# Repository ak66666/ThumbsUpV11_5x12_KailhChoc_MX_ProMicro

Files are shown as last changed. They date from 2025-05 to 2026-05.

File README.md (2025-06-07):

# ThumbsUp! v11 5x12 Keyboard for Kailh Choc and MX-compatible switches dirven by ProMicro and pin-compatibles

Multilevel 58 Key Ergonomic Contoured Mechanical Keyboard.

A variant of v5 and v8 for this specific combination of switches, plus with extra pins for MCU to make ProGlide Cirque touchpad work in ZMK.
Added slots on the PCBs to cut off the top row and outer columns, to turn the board into a 4x12 or 5x10 or 4x10, moved the tracks out of the way for those cuts.

The board uses Kailh Choc and MX-compatible switches with hot-swap sockets.

ProMicro or pin-compatible MCUs are supported, including Raspberry RP2040, nice!nano v2 and clones.

Supports Proglide Cirque touchpad (up to 40mm diameter).

Can be made wireless with nice!nano v2 (or a clone) and a battery, [ZMK firmware.](https://github.com/ak66666/zmk-config/tree/master)

# Photos

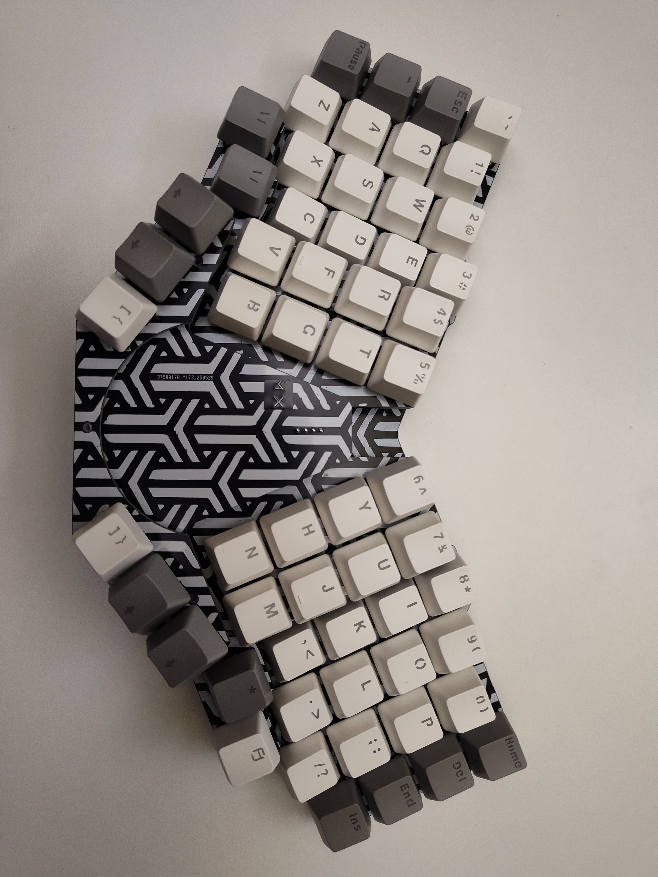
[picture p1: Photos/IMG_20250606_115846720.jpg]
v11 complete with MX switches and caps

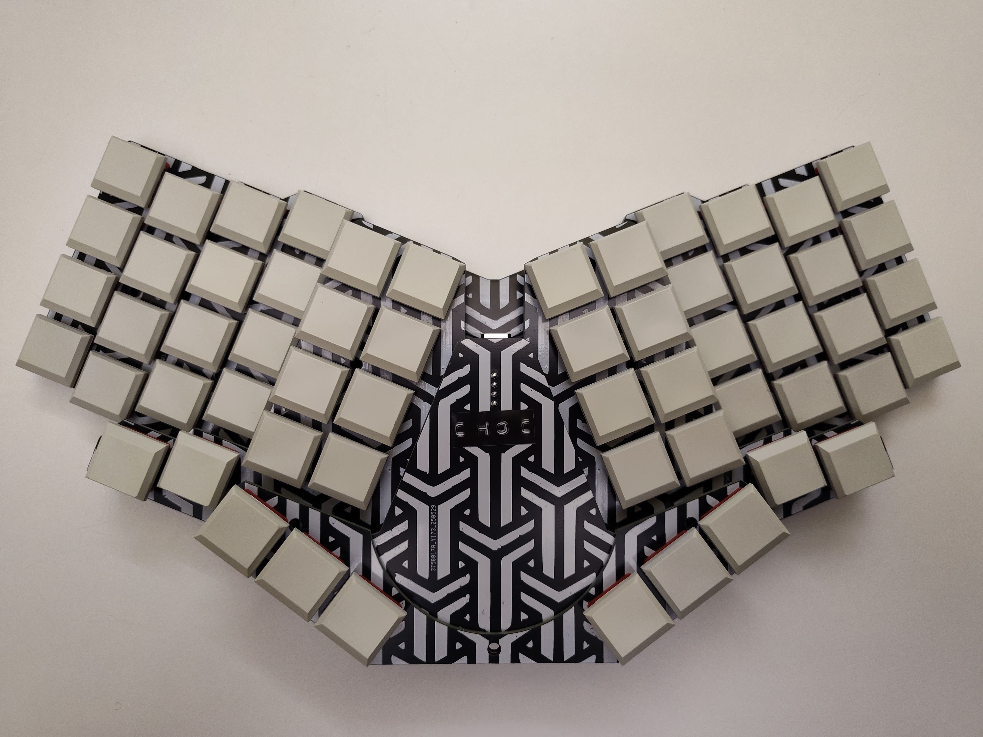
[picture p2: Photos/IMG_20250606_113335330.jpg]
v11 complete with Kailh Choc switches and caps

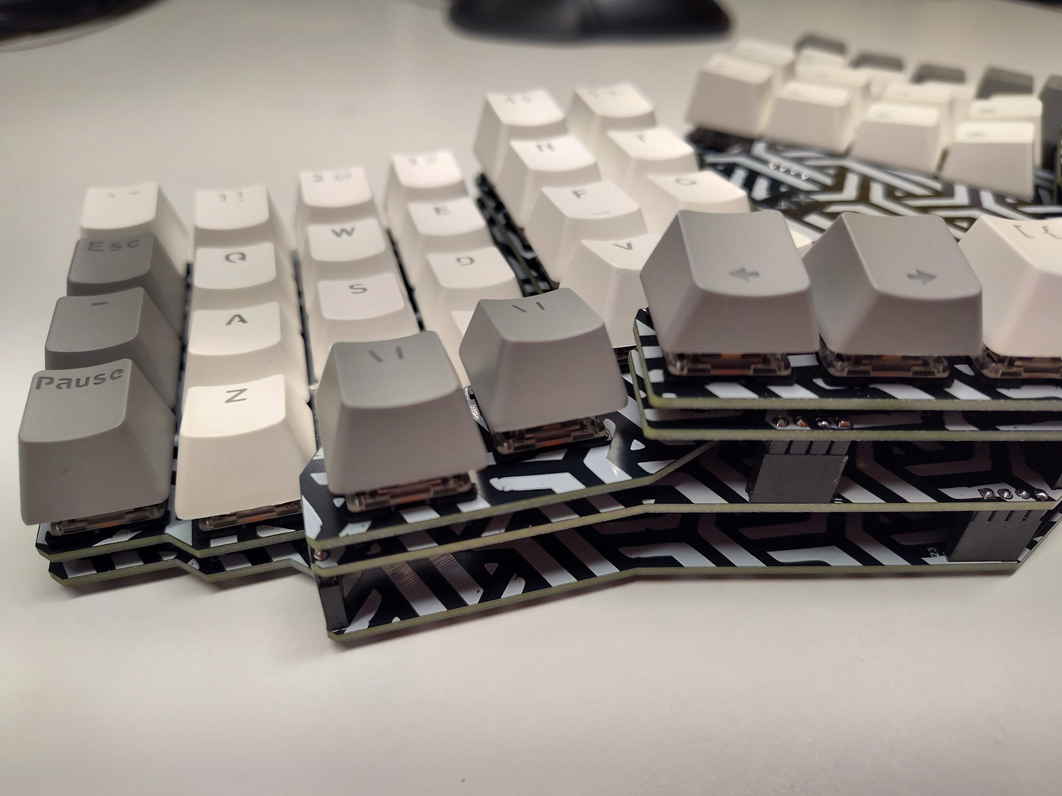
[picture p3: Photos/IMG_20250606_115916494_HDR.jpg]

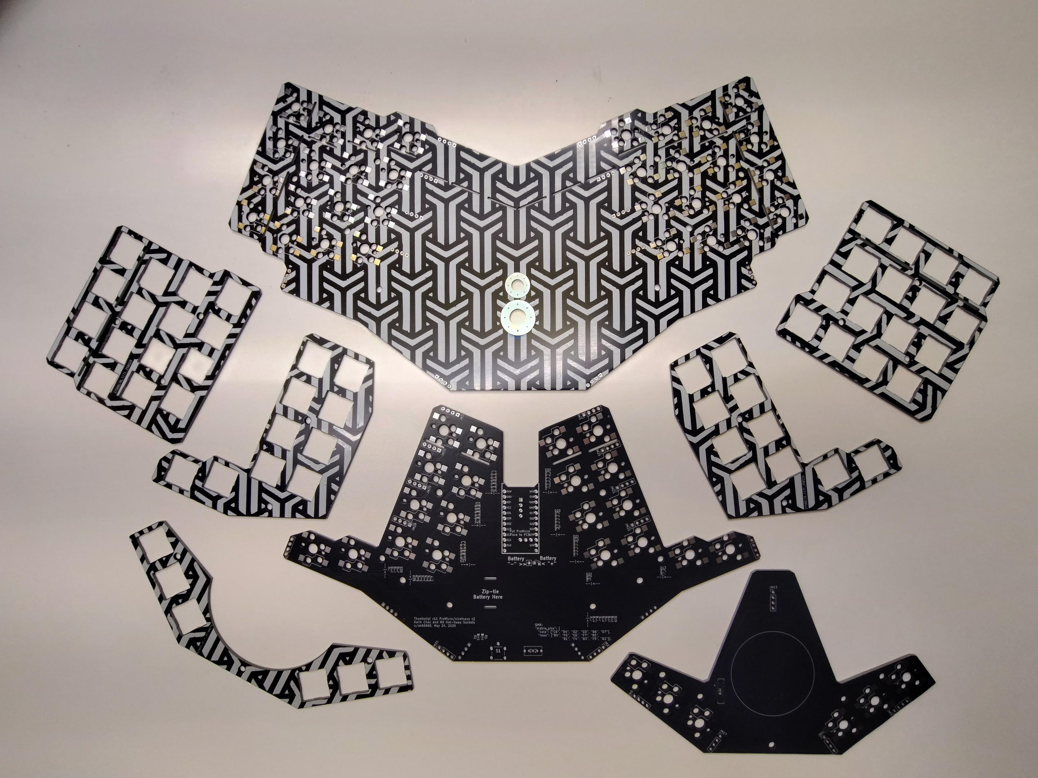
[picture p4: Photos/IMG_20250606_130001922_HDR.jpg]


See more pictures in Photos folder. 

# Firmware
Default firmware is here:
QMK Firmware
Note this board uses the firmware from v5 - it got the very same wiring.

# Here you can buy it
ThumbsUp! v11

# More info

Usage instructions and miscellaneous info:
Blogspot

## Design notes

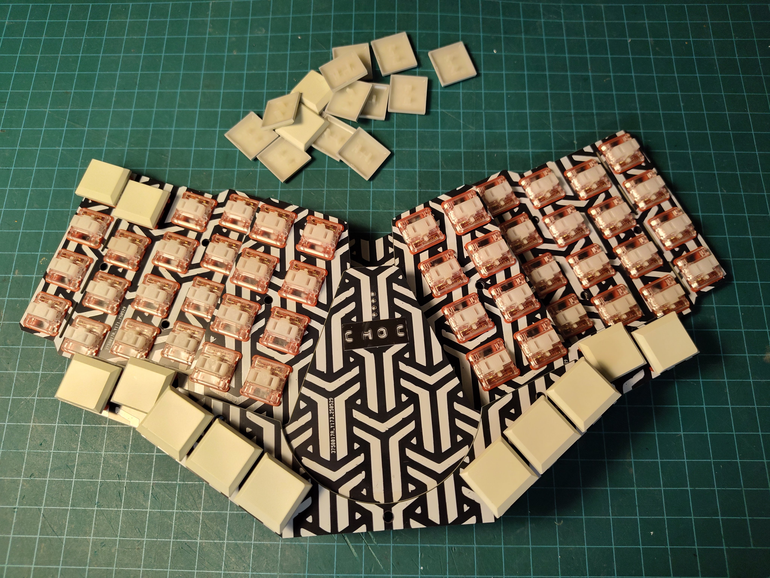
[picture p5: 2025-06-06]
Photos/IMG_20250606_111325914_HDR.jpg

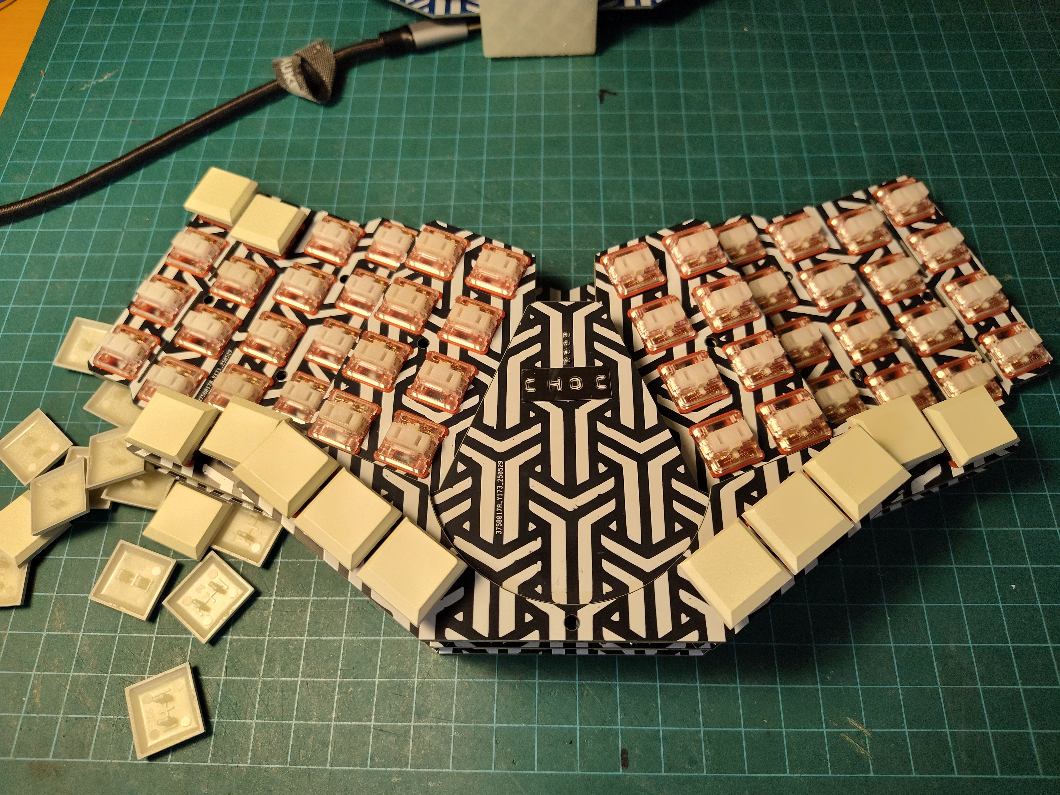
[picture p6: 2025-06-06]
Photos/IMG_20250606_111258978_HDR.jpg

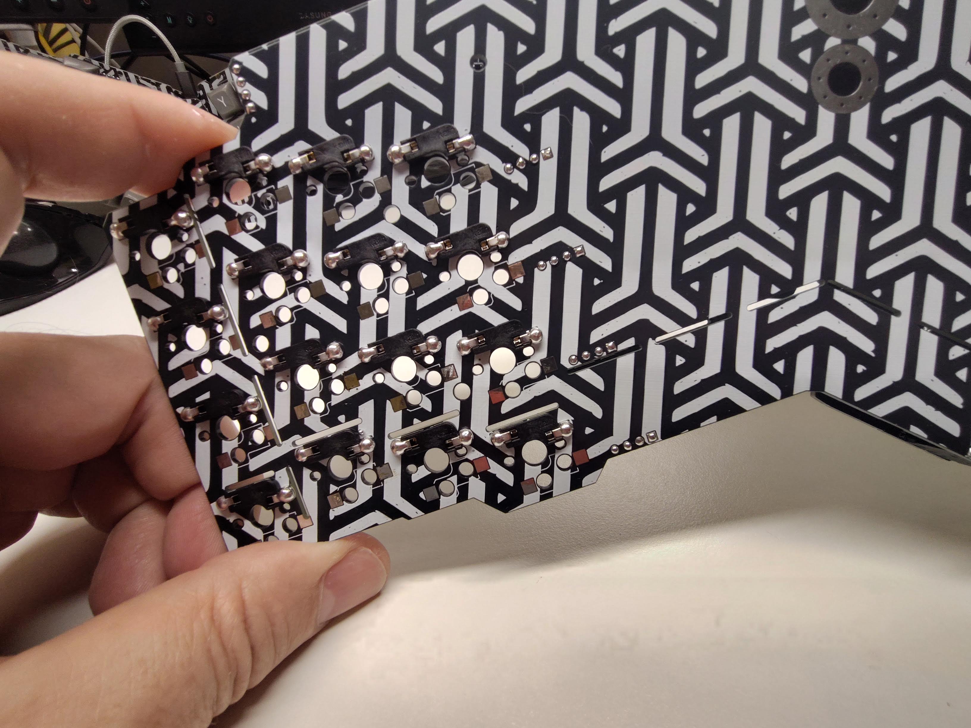
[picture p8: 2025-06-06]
Photos/IMG_20250605_220522538_HDR.jpg

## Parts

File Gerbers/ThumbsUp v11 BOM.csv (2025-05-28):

Designator | Footprint | Quantity | Comment | JLCPCB Part #
D49,D50,D55,D54,D57,D56,D52,D58,D51,D14,D53,D35,D34,D42,D40,D48,D45,D43,D46,D47,D38,D41,D39,D37,D36,D44,D33,D32,D31,D16,D15,D13,D12,D30,D29,D27,D25,D28,D24,D22,D21,D23,D20,D19,D26,D18,D17,D5,D7,D4,D6,D9,D10,D1,D8,D11,D3,D2 | D_SOD-523 | 58 | D_Small | C27748
R2,R1 | R_0805_2012Metric | 2 | 5.1K | C27834

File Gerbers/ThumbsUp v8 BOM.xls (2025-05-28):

Comment | Designator | Footprint | JLCPCB Part #
D_Small | D58,D57,D56,D55,D54,D53,D52,D51,D50,D49,D48,D47,D46,D45,D44,D43,D42,D41,D40,D39,D38,D37,D36,D35,D34,D33,D32,D31,D30,D29,D28,D27,D26,D25,D24,D23,D22,D21,D20,D19,D18,D17,D16,D15,D14,D13,D12,D11,D10,D9,D8,D7,D6,D5,D4,D3,D2,D1 | D_SOD-123 | C81598
5.1K | R2,R1 | R_0805_2012Metric | C27834

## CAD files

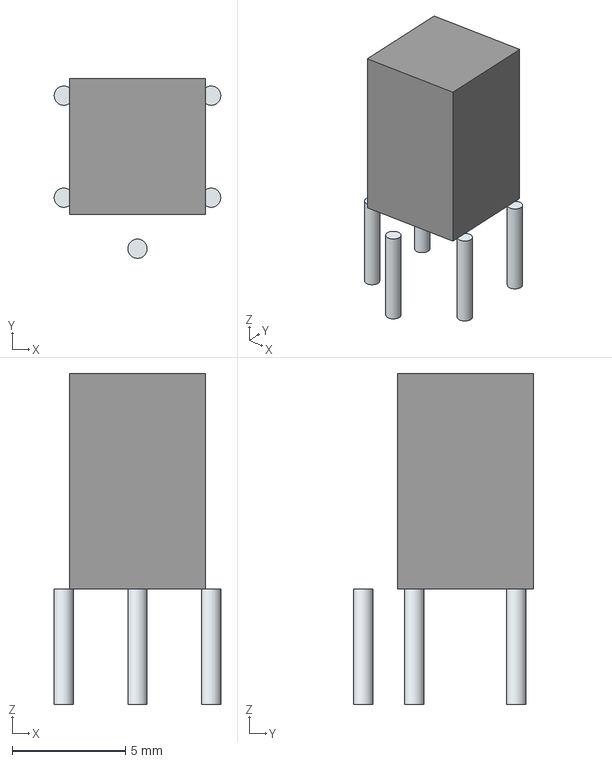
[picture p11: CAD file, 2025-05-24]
LIB_BUTT-4/BUTT-4/3D/BUTT-4.stp
7.35 x 7.92 x 14.6 mm
Leads x 5

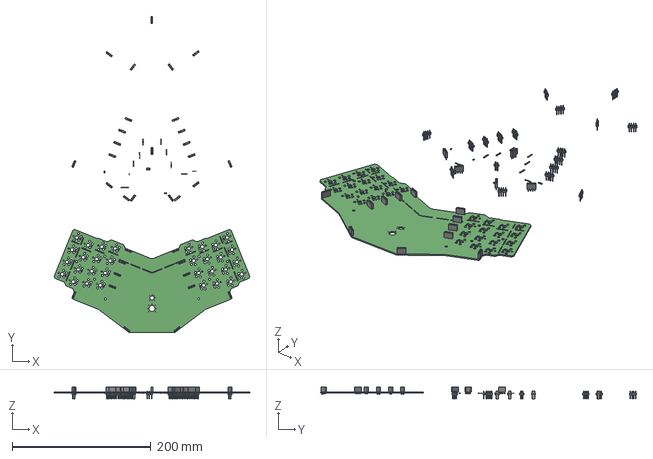
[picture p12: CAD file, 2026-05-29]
ThumbsUp_v11.step
282.0 x 455.3 x 17.2 mm

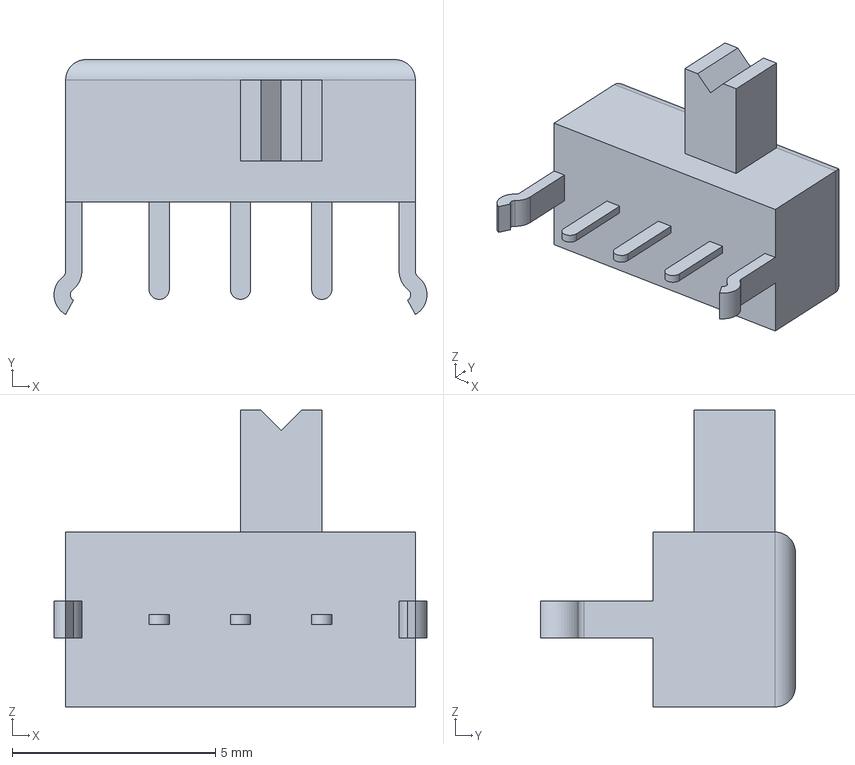
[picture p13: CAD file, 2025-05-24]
1825232-1/3D/1825232-1.stp
9.17 x 6.27 x 7.30 mm

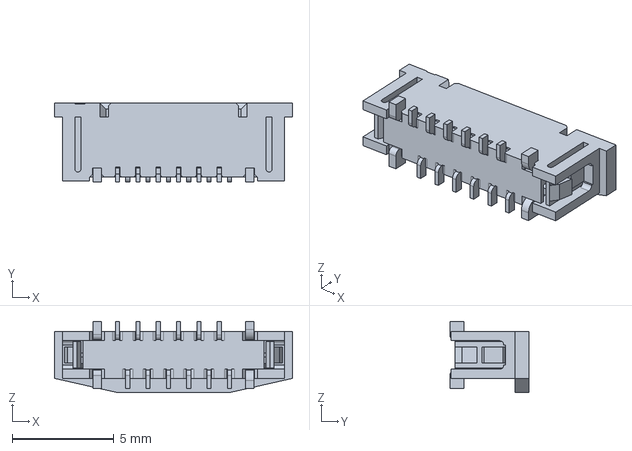
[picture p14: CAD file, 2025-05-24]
Molex 52559-1233/52559-1233/3D/52559-1233.stp
11.7 x 3.90 x 3.50 mm

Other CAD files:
1825232-1/Allegro/18252321.psm
1825232-1/DEHDL/1825232_1/chips/chips.prt
LIB_BUTT-4/BUTT-4/Allegro/butt4.psm
LIB_BUTT-4/BUTT-4/DEHDL/butt_4/chips/chips.prt
Molex 52559-1233/52559-1233/Allegro/525591233.psm
Molex 52559-1233/52559-1233/DEHDL/52559_1233/chips/chips.prt

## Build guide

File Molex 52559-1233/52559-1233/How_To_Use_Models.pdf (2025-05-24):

ECAD PART WIZARD.

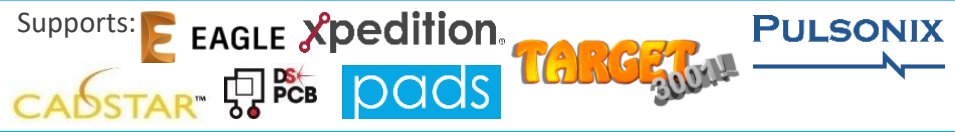
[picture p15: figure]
Supports:

Offers engineers full control of the symbol fracturing and symbol pin positions (left, right, top, bottom). ECAD Symbols & footprints can be downloaded directly from within the EPW application or from manufacturer and RS Component website.

DOWNLOAD: http://componentsearchengine.com/EPW.html

LIBRARY LOADER.
Allows Engineers to click our icon from any webpage and it injects the symbols and footprint directly into your chosen library and attached them to your cursor ready for placement.

DOWNLOAD: http://componentsearchengine.com/LibraryLoader.php

SamacSys is a leading developer of software tools for creating and managing electronic component ECAD data.

## 3 ways to use our ECAD Schematic Symbols & PCB footprints

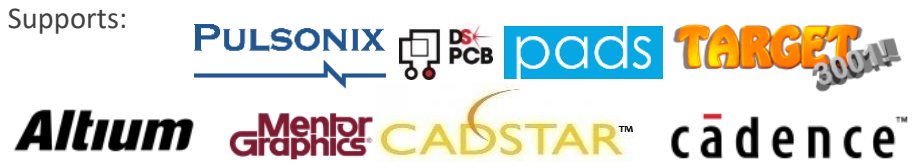
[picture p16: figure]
Supports:

DIRECT MODEL DOWNLOAD FOR MANUAL USE.
Our Schematic Symbols and PCB Footprint can be downloaded in a zip file for the user to manually load into their existing ECAD Library.

DOWNLOAD: http://componentsearchengine.com

Automatically load
models into your
library and attach
them to your cursor
by clicking our icon
on any website.

WATCH VIDEO (https://componentsearchengine.com/pcb-libraries.php)

Excel plug in. Search
for parts from within
Excel, customise the
fracturing and export
to your chosen ECAD
Tool.

WATCH VIDEO (http://www.samacsys.com/epw/)

You may download our
symbols & footprints in
the format of your
ECAD system for
manually loading into
your library.

MORE INFO (http://www.samacsys.com/pcb-part-libraries/)

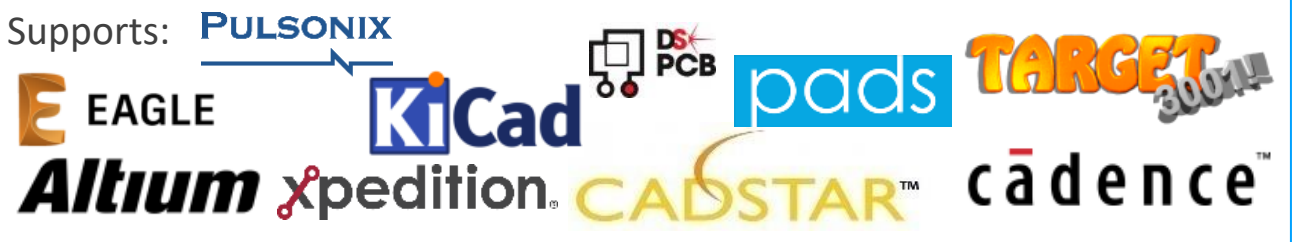
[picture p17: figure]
Supports:

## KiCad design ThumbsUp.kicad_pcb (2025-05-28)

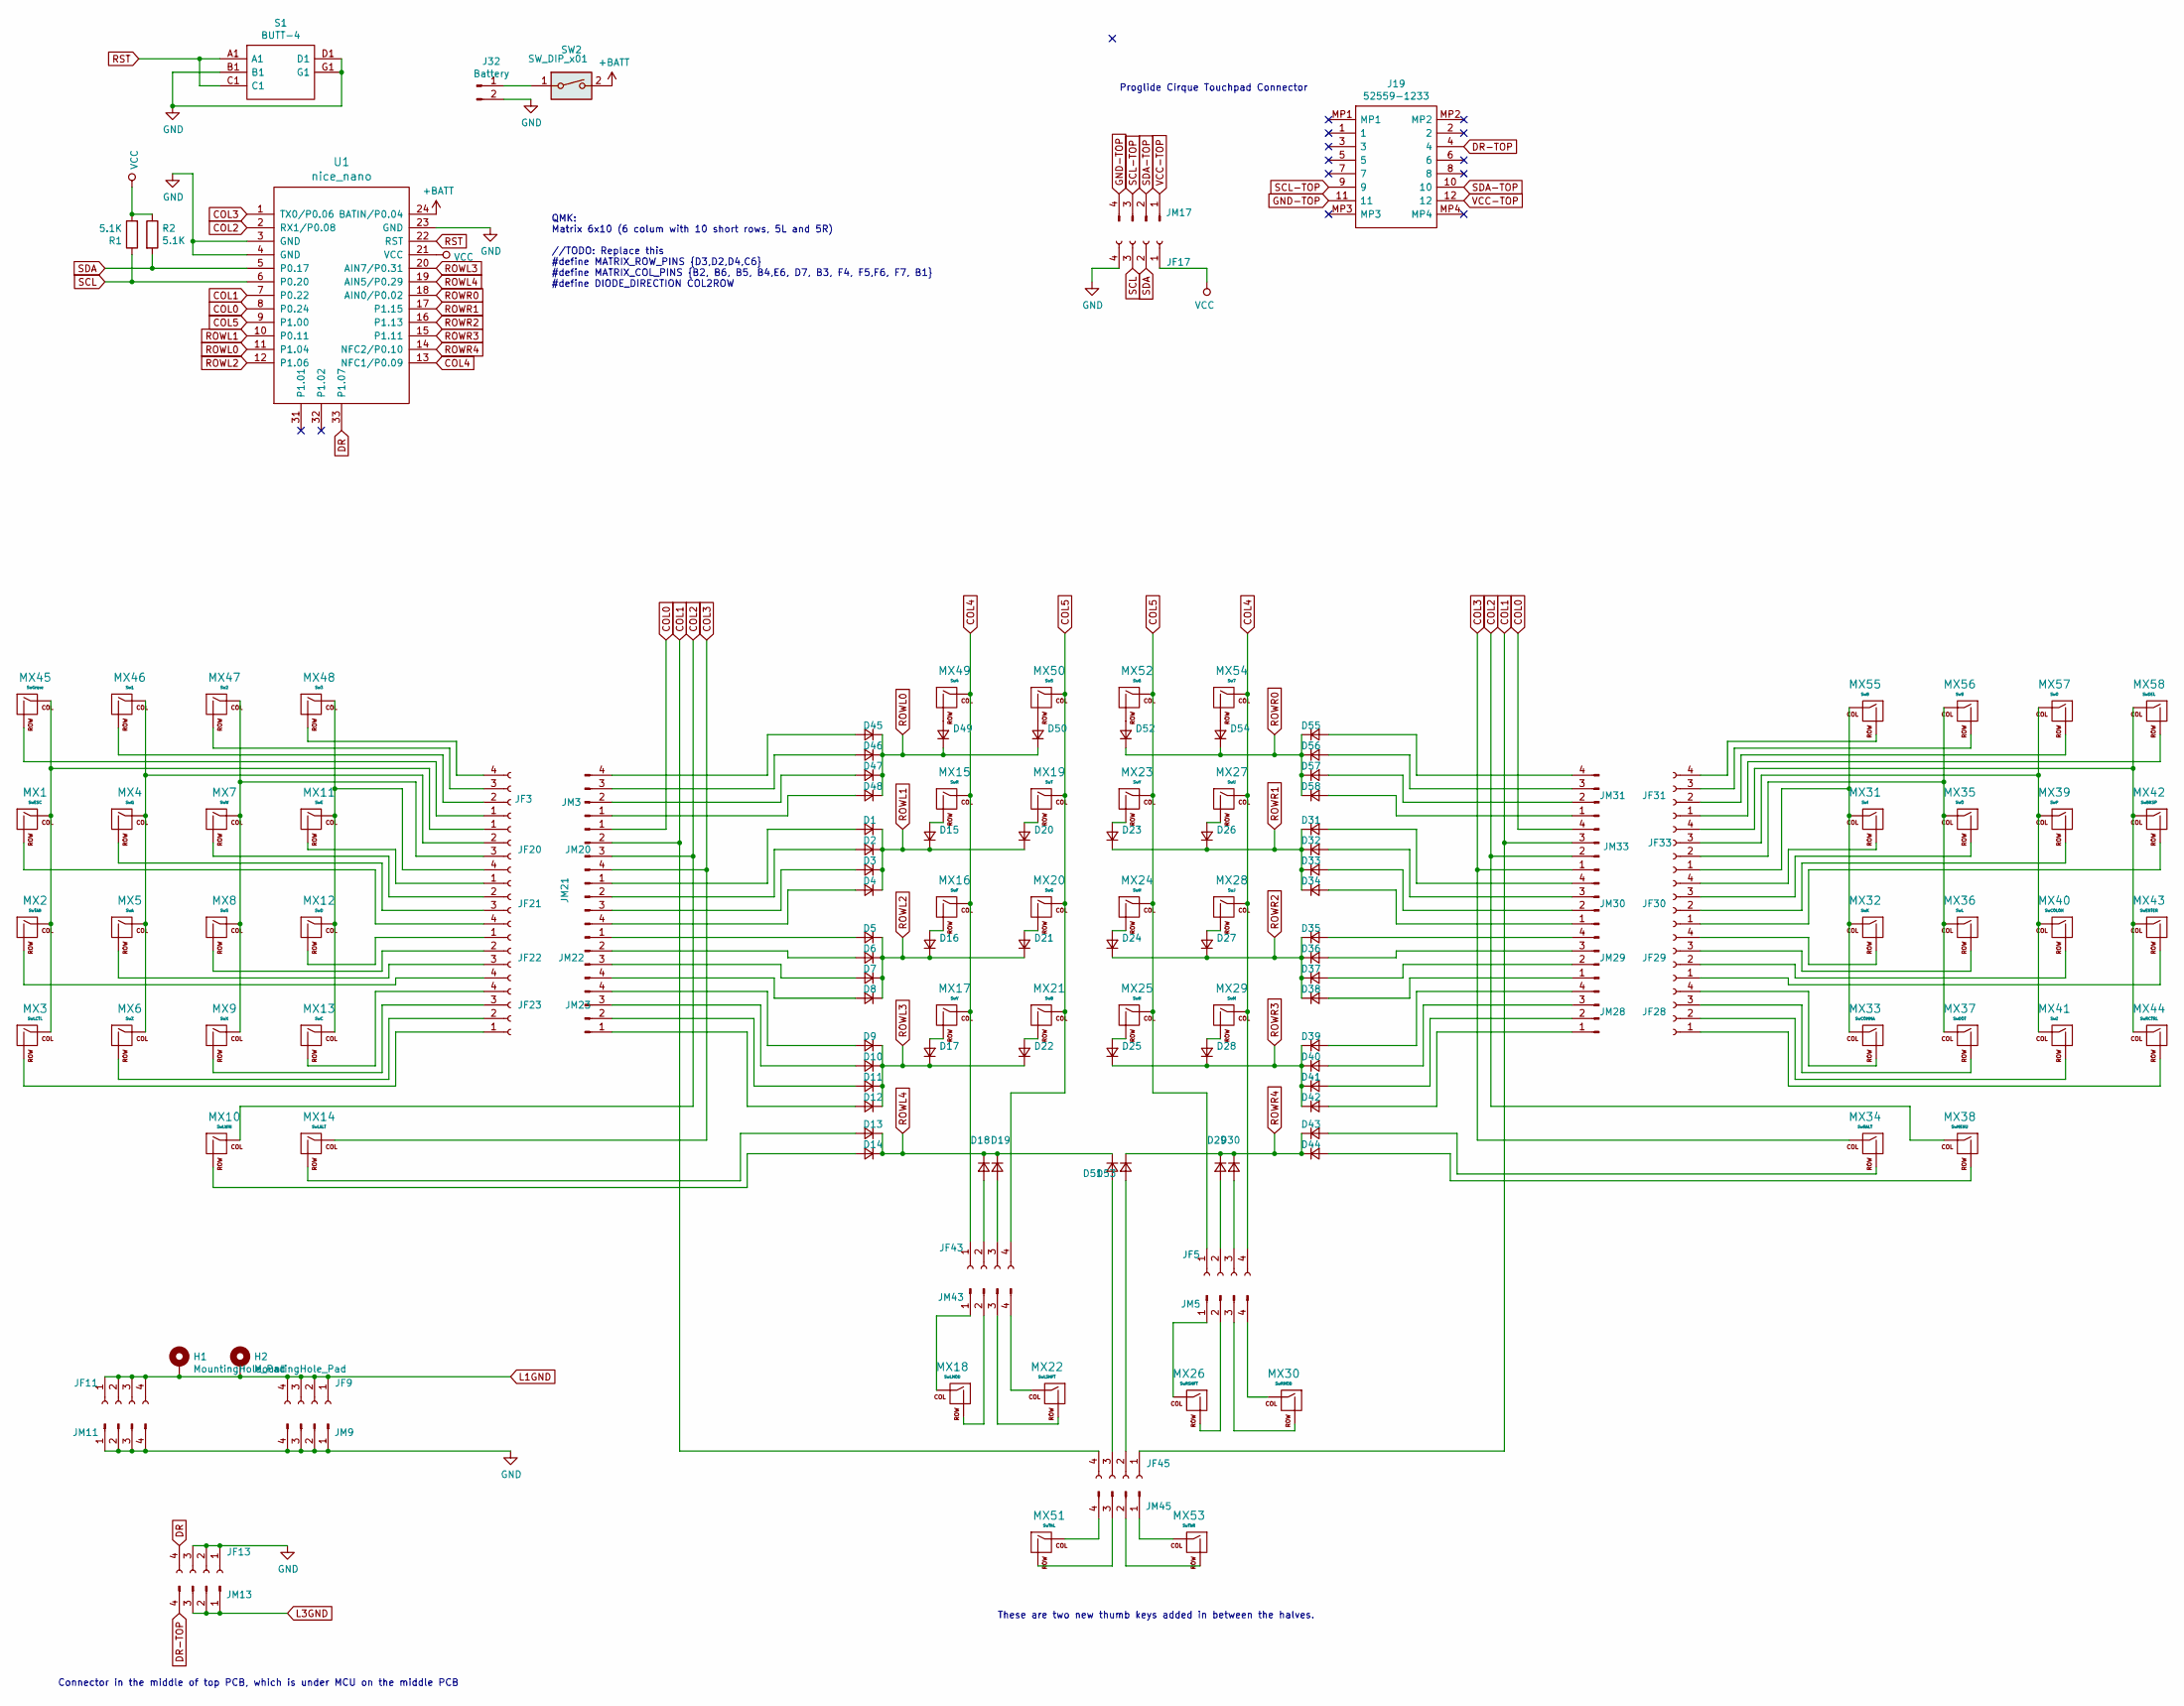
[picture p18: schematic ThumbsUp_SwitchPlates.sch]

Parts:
D1, D2, D3, D4, D5, D6, D7, D8, D9, D10, D11, D12, D13, D14, D15, D16, D17, D18, D19, D20, D21, D22, D23, D24, D25, D26, D27, D28, D29, D30, D31, D32, D33, D34, D35, D36, D37, D38, D39, D40, D41, D42, D43, D44, D45, D46, D47, D48, D49, D50, D51, D52, D53, D54, D55, D56, D57, D58: D_Small; D_SOD-523
H1: MountingHole_Pad; MountingHole_6mm_Pad_Via
H2: MountingHole_Pad; MountingHole_8.4mm_M8_Pad_Via
J19: 52559-1233; 525591233; Mouser Part Number 538-52559-1233
J32: Battery; PinHeader_1x02_P2.54mm_Vertical
JF3, JF5, JF20, JF21, JF22, JF23, JF28, JF29, JF30, JF31, JF33, JF43, JF45: Conn_01x04_Female; PinSocket_1x04_P2.54mm_Vertical
JF9, JF11, JF13, JF17: Raiser_Female; PinSocket_1x04_P2.54mm_Vertical
JM3, JM20, JM21, JM22, JM23, JM28, JM29, JM30, JM31, JM33, JM43, JM45: Conn_01x04_Male; PinHeader_1x04_P2.54mm_Vertical
JM5: Male; PinHeader_1x04_P2.54mm_Vertical
JM9, JM11, JM13, JM17: Raiser_Male; PinHeader_1x04_P2.54mm_Vertical
MX1: SwESC; PG1350_MX_sockets
MX2: SwTAB; PG1350_MX_sockets
MX3: SwLCTL; PG1350_MX_sockets
MX4: SwQ; PG1350_MX_sockets
MX5: SwA; PG1350_MX_sockets
MX6: SwZ; PG1350_MX_sockets
MX7: SwW; PG1350_MX_sockets
MX8: SwS; PG1350_MX_sockets
MX9: SwX; PG1350_MX_sockets
MX10: SwLWIN; PG1350_MX_sockets
MX11: SwE; PG1350_MX_sockets
MX12: SwD; PG1350_MX_sockets
MX13: SwC; PG1350_MX_sockets
MX14: SwLALT; PG1350_MX_sockets
MX15: SwR; PG1350_MX_sockets
MX16: SwF; PG1350_MX_sockets
MX17: SwV; PG1350_MX_sockets
MX18: SwLMOD; PG1350_MX_sockets
MX19: SwT; PG1350_MX_sockets
MX20: SwG; PG1350_MX_sockets
MX21: SwB; PG1350_MX_sockets
MX22: SwLSHFT; PG1350_MX_sockets
MX23: SwY; PG1350_MX_sockets
MX24: SwH; PG1350_MX_sockets
MX25: SwN; PG1350_MX_sockets
MX26: SwRSHFT; PG1350_MX_sockets
MX27: SwU; PG1350_MX_sockets
MX28: SwJ; PG1350_MX_sockets
MX29: SwM; PG1350_MX_sockets
MX30: SwRMOD; PG1350_MX_sockets
MX31: SwI; PG1350_MX_sockets
MX32: SwK; PG1350_MX_sockets
MX33: SwCOMMA; PG1350_MX_sockets
MX34: SwRALT; PG1350_MX_sockets
MX35: SwO; PG1350_MX_sockets
MX36: SwL; PG1350_MX_sockets
MX37: SwDOT; PG1350_MX_sockets
MX38: SwMENU; PG1350_MX_sockets
MX39: SwP; PG1350_MX_sockets
MX40: SwCOLON; PG1350_MX_sockets
MX41: Sw?; PG1350_MX_sockets
MX42: SwBKSP; PG1350_MX_sockets
MX43: SwENTER; PG1350_MX_sockets
MX44: SwRCTRL; PG1350_MX_sockets
MX45: SwGrave; PG1350_MX_sockets
MX46: Sw1; PG1350_MX_sockets
MX47: Sw2; PG1350_MX_sockets
MX48: Sw3; PG1350_MX_sockets
MX49: Sw4; PG1350_MX_sockets
MX50: Sw5; PG1350_MX_sockets
MX51: SwThL; PG1350_MX_sockets
MX52: Sw6; PG1350_MX_sockets
MX53: SwThR; PG1350_MX_sockets
MX54: Sw7; PG1350_MX_sockets
MX55: Sw8; PG1350_MX_sockets
MX56: Sw9; PG1350_MX_sockets
MX57: Sw0; PG1350_MX_sockets
MX58: SwDEL; PG1350_MX_sockets
R1, R2: 5.1K; R_0805_2012Metric
S1: BUTT-4; BUTT4; Manufacturer_Part_Number BUTT-4; Mouser Part Number 992-BUTT-4
SW2: SW_DIP_x01; 18252321
U1: nice_nano

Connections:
+BATT: SW2.2, U1.24 (BATIN/P0.04)
COL0: JM20.1, JM33.4, U1.8 (P0.24)
COL1: JF45.1, JF45.4, JM20.2, JM33.3, U1.7 (P0.22)
COL2: JM20.3, JM33.2, MX10.1 (COL), MX38.1 (COL), U1.2 (RX1/P0.08)
COL3: JM20.4, JM33.1, MX14.1 (COL), MX34.1 (COL), U1.1 (TX0/P0.06)
COL4: JF5.4, JF43.1, MX15.1 (COL), MX16.1 (COL), MX17.1 (COL), MX27.1 (COL), MX28.1 (COL), MX29.1 (COL), MX49.1 (COL), MX54.1 (COL), U1.13 (NFC1/P0.09)
COL5: JF5.1, JF43.4, MX19.1 (COL), MX20.1 (COL), MX21.1 (COL), MX23.1 (COL), MX24.1 (COL), MX25.1 (COL), MX50.1 (COL), MX52.1 (COL), U1.9 (P1.00)
DR: JF13.4, U1.33 (P1.07)
DR-TOP: J19.4, JM13.4
GND: J32.2, JF13.1, JF13.2, JF13.3, JF17.4, JM9.1, JM9.2, JM9.3, JM9.4, JM11.1, JM11.2, JM11.3, JM11.4, S1.B1, S1.D1, S1.G1, U1.3 (GND), U1.4 (GND), U1.23 (GND)
GND-TOP: J19.11, JM17.4
L1GND: H1.1, H2.1, JF9.1, JF9.2, JF9.3, JF9.4, JF11.1, JF11.2, JF11.3, JF11.4
L3GND: JM13.1, JM13.2, JM13.3
unnamed: D1.2 (A), JM21.1
unnamed: D2.2 (A), JM21.2
unnamed: D3.2 (A), JM21.3
unnamed: D4.2 (A), JM21.4
unnamed: D5.2 (A), JM22.1
unnamed: D6.2 (A), JM22.2
unnamed: D7.2 (A), JM22.3
unnamed: D8.2 (A), JM22.4
unnamed: D9.2 (A), JM23.4
unnamed: D10.2 (A), JM23.3
unnamed: D11.2 (A), JM23.2
unnamed: D12.2 (A), JM23.1
unnamed: D13.2 (A), MX14.2 (ROW)
unnamed: D14.2 (A), MX10.2 (ROW)
unnamed: D15.2 (A), MX15.2 (ROW)
unnamed: D16.2 (A), MX16.2 (ROW)
unnamed: D17.2 (A), MX17.2 (ROW)
unnamed: D18.2 (A), JF43.2
unnamed: D19.2 (A), JF43.3
unnamed: D20.2 (A), MX19.2 (ROW)
unnamed: D21.2 (A), MX20.2 (ROW)
unnamed: D22.2 (A), MX21.2 (ROW)
unnamed: D23.2 (A), MX23.2 (ROW)
unnamed: D24.2 (A), MX24.2 (ROW)
unnamed: D25.2 (A), MX25.2 (ROW)
unnamed: D26.2 (A), MX27.2 (ROW)
unnamed: D27.2 (A), MX28.2 (ROW)
unnamed: D28.2 (A), MX29.2 (ROW)
unnamed: D29.2 (A), JF5.2
unnamed: D30.2 (A), JF5.3
unnamed: D31.2 (A), JM30.4
unnamed: D32.2 (A), JM30.3
unnamed: D33.2 (A), JM30.2
unnamed: D34.2 (A), JM30.1
unnamed: D35.2 (A), JM29.4
unnamed: D36.2 (A), JM29.3
unnamed: D37.2 (A), JM29.2
unnamed: D38.2 (A), JM29.1
unnamed: D39.2 (A), JM28.4
unnamed: D40.2 (A), JM28.3
unnamed: D41.2 (A), JM28.2
unnamed: D42.2 (A), JM28.1
unnamed: D43.2 (A), MX34.2 (ROW)
unnamed: D44.2 (A), MX38.2 (ROW)
unnamed: D45.2 (A), JM3.4
unnamed: D46.2 (A), JM3.3
unnamed: D47.2 (A), JM3.2
unnamed: D48.2 (A), JM3.1
unnamed: D49.2 (A), MX49.2 (ROW)
unnamed: D50.2 (A), MX50.2 (ROW)
unnamed: D51.2 (A), JF45.3
unnamed: D52.2 (A), MX52.2 (ROW)
unnamed: D53.2 (A), JF45.2
unnamed: D54.2 (A), MX54.2 (ROW)
unnamed: D55.2 (A), JM31.4
unnamed: D56.2 (A), JM31.3
unnamed: D57.2 (A), JM31.2
unnamed: D58.2 (A), JM31.1
unnamed: J32.1, SW2.1
unnamed: JF3.1, MX45.2 (ROW)
unnamed: JF3.2, MX46.2 (ROW)
unnamed: JF3.3, MX47.2 (ROW)
unnamed: JF3.4, MX48.2 (ROW)
unnamed: JF20.1, MX1.1 (COL), MX2.1 (COL), MX3.1 (COL), MX45.1 (COL)
unnamed: JF20.2, MX4.1 (COL), MX5.1 (COL), MX6.1 (COL), MX46.1 (COL)
unnamed: JF20.3, MX7.1 (COL), MX8.1 (COL), MX9.1 (COL), MX47.1 (COL)
unnamed: JF20.4, MX11.1 (COL), MX12.1 (COL), MX13.1 (COL), MX48.1 (COL)
unnamed: JF21.1, MX11.2 (ROW)
unnamed: JF21.2, MX7.2 (ROW)
unnamed: JF21.3, MX4.2 (ROW)
unnamed: JF21.4, MX1.2 (ROW)
unnamed: JF22.1, MX12.2 (ROW)
unnamed: JF22.2, MX8.2 (ROW)
unnamed: JF22.3, MX5.2 (ROW)
unnamed: JF22.4, MX2.2 (ROW)
unnamed: JF23.1, MX3.2 (ROW)
unnamed: JF23.2, MX6.2 (ROW)
unnamed: JF23.3, MX9.2 (ROW)
unnamed: JF23.4, MX13.2 (ROW)
unnamed: JF28.1, MX44.2 (ROW)
unnamed: JF28.2, MX41.2 (ROW)
unnamed: JF28.3, MX37.2 (ROW)
unnamed: JF28.4, MX33.2 (ROW)
unnamed: JF29.1, MX43.2 (ROW)
unnamed: JF29.2, MX40.2 (ROW)
unnamed: JF29.3, MX36.2 (ROW)
unnamed: JF29.4, MX32.2 (ROW)
unnamed: JF30.1, MX42.2 (ROW)
unnamed: JF30.2, MX39.2 (ROW)
unnamed: JF30.3, MX35.2 (ROW)
unnamed: JF30.4, MX31.2 (ROW)
unnamed: JF31.1, MX58.2 (ROW)
unnamed: JF31.2, MX57.2 (ROW)
unnamed: JF31.3, MX56.2 (ROW)
unnamed: JF31.4, MX55.2 (ROW)
unnamed: JF33.1, MX31.1 (COL), MX32.1 (COL), MX33.1 (COL), MX55.1 (COL)
unnamed: JF33.2, MX35.1 (COL), MX36.1 (COL), MX37.1 (COL), MX56.1 (COL)
unnamed: JF33.3, MX39.1 (COL), MX40.1 (COL), MX41.1 (COL), MX57.1 (COL)
unnamed: JF33.4, MX42.1 (COL), MX43.1 (COL), MX44.1 (COL), MX58.1 (COL)
unnamed: JM5.1, MX26.1 (COL)
unnamed: JM5.2, MX26.2 (ROW)
unnamed: JM5.3, MX30.2 (ROW)
unnamed: JM5.4, MX30.1 (COL)
unnamed: JM43.1, MX18.1 (COL)
unnamed: JM43.2, MX18.2 (ROW)
unnamed: JM43.3, MX22.2 (ROW)
unnamed: JM43.4, MX22.1 (COL)
unnamed: JM45.1, MX53.1 (COL)
unnamed: JM45.2, MX53.2 (ROW)
unnamed: JM45.3, MX51.2 (ROW)
unnamed: JM45.4, MX51.1 (COL)
ROWL0: D45.1 (K), D46.1 (K), D47.1 (K), D48.1 (K), D49.1 (K), D50.1 (K), U1.11 (P1.04)
ROWL1: D1.1 (K), D2.1 (K), D3.1 (K), D4.1 (K), D15.1 (K), D20.1 (K), U1.10 (P0.11)
ROWL2: D5.1 (K), D6.1 (K), D7.1 (K), D8.1 (K), D16.1 (K), D21.1 (K), U1.12 (P1.06)
ROWL3: D9.1 (K), D10.1 (K), D11.1 (K), D12.1 (K), D17.1 (K), D22.1 (K), U1.20 (AIN7/P0.31)
ROWL4: D13.1 (K), D14.1 (K), D18.1 (K), D19.1 (K), D51.1 (K), U1.19 (AIN5/P0.29)
ROWR0: D52.1 (K), D54.1 (K), D55.1 (K), D56.1 (K), D57.1 (K), D58.1 (K), U1.18 (AIN0/P0.02)
ROWR1: D23.1 (K), D26.1 (K), D31.1 (K), D32.1 (K), D33.1 (K), D34.1 (K), U1.17 (P1.15)
ROWR2: D24.1 (K), D27.1 (K), D35.1 (K), D36.1 (K), D37.1 (K), D38.1 (K), U1.16 (P1.13)
ROWR3: D25.1 (K), D28.1 (K), D39.1 (K), D40.1 (K), D41.1 (K), D42.1 (K), U1.15 (P1.11)
ROWR4: D29.1 (K), D30.1 (K), D43.1 (K), D44.1 (K), D53.1 (K), U1.14 (NFC2/P0.10)
RST: S1.A1, S1.C1, U1.22 (RST)
SCL: JF17.3, R1.1, U1.6 (P0.20)
SCL-TOP: J19.9, JM17.3
SDA: JF17.2, R2.2, U1.5 (P0.17)
SDA-TOP: J19.10, JM17.2
VCC: JF17.1, R1.2, R2.1, U1.21 (VCC)
VCC-TOP: J19.12, JM17.1

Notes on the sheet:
QMK: Matrix 6x10 (6 colum with 10 short rows, 5L and 5R) //TODO: Replace this #define MATRIX_ROW_PINS {D3,D2,D4,C6} #define MATRIX_COL_PINS {B2, B6, B5, B4,E6, D7, B3, F4, F5,F6, F7, B1} #define DIODE_DIRECTION COL2ROW
Proglide Cirque Touchpad Connector
These are two new thumb keys added in between the halves.
Connector in the middle of top PCB, which is under MCU on the middle PCB

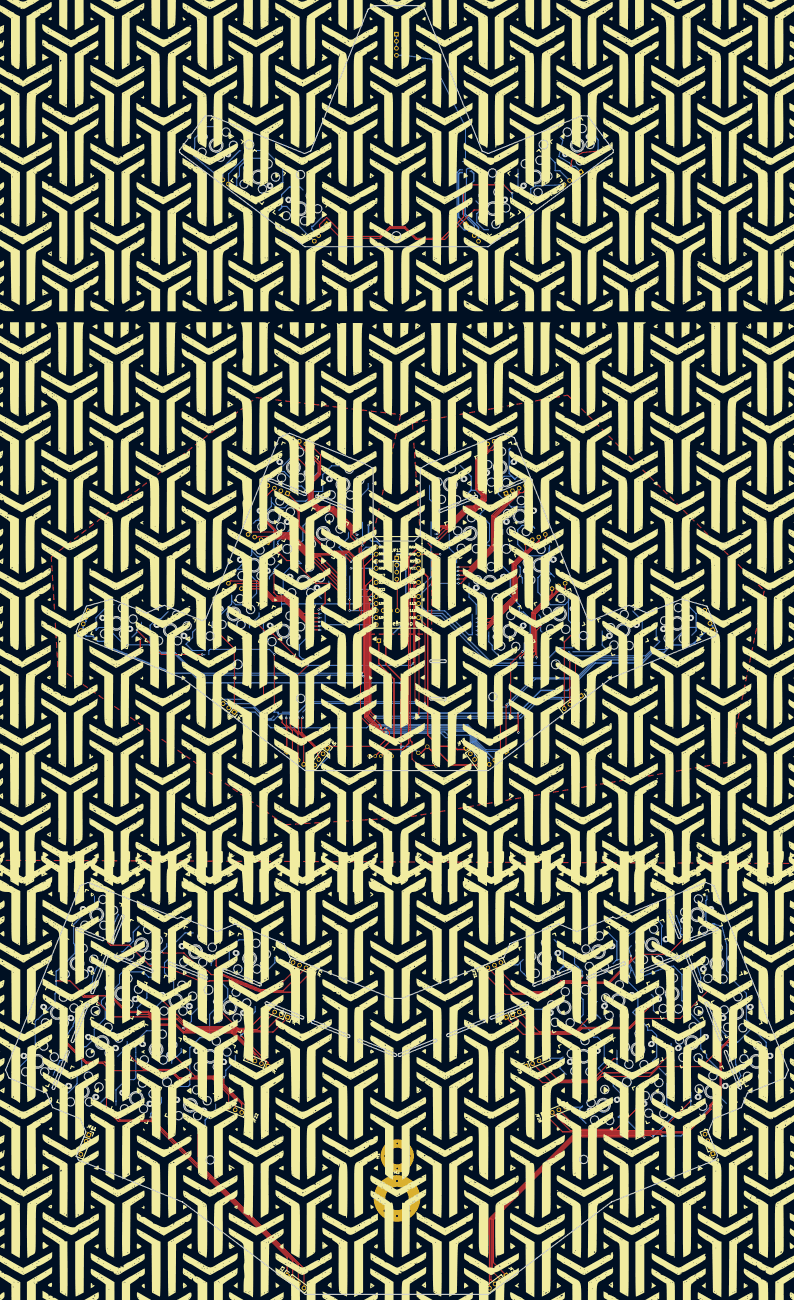
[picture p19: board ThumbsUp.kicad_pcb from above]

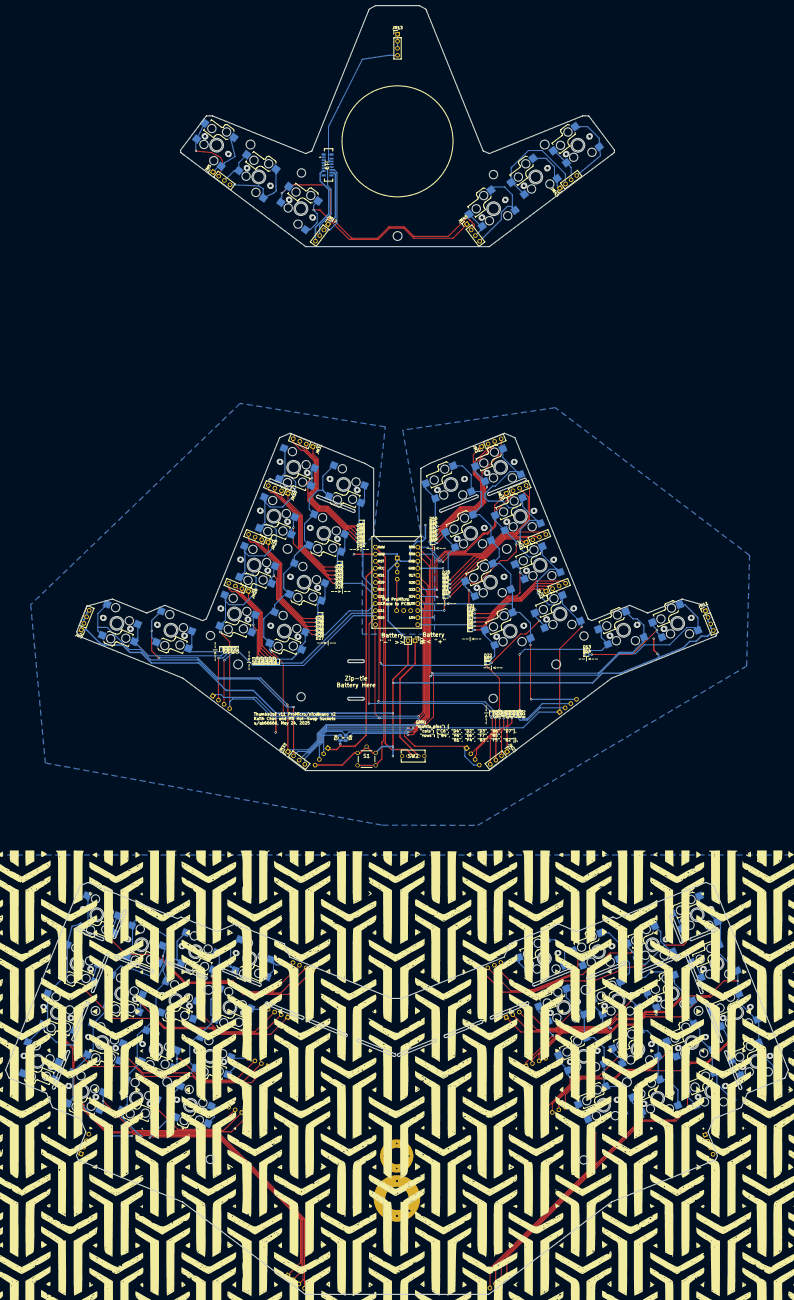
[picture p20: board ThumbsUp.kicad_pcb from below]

Board: 2 copper layers, 282.0 x 464.4 mm, 159 parts (81 on the bottom side), 141 nets.

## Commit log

2025-05-24 Cloned v8 into v11, no changes to the design yet.
    [1825232-1.SchLib, 1825232-1.stp, 18252321.PcbLib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]
2025-05-24 Updated the schematics, replaced the switches with MX/Kailh Choc combo
    [ThumbsUp.kicad_pcb, ThumbsUp.sch]
2025-05-25 Replaced the diodes to the tiny D523 ones, started the tracks.
    [ThumbsUp.kicad_pcb, ThumbsUp.sch]
2025-05-26 Laid out the middle PCB.
    [ThumbsUp.kicad_pcb]
2025-05-26 Added connector holes for the switch panels.
    [ThumbsUp.kicad_pcb]
2025-05-26 Laid out the top PCB.
    [ThumbsUp.kicad_pcb]
2025-05-27 Laid out the bottom PCB.
    [ThumbsUp.kicad_pcb]
2025-05-27 Added a project for the switch plates.
    [ThumbsUp_SwitchPlates.kicad_pcb, ThumbsUp_SwitchPlates.sch]
2025-05-27 Added silkscreens.
    [ThumbsUp.kicad_pcb, ThumbsUp_SwitchPlates.kicad_pcb]
2025-05-28 Added solder mask areas to trim the silkscreen outside of the pcb.
    [ThumbsUp_SwitchPlates-B_Adhes.gbr, ThumbsUp_SwitchPlates-B_CrtYd.gbr, ThumbsUp_SwitchPlates-B_Cu.gbr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]
2025-05-28 Added solder mask areas to trim the silkscreen outside of the pcb - for L2.
    [ThumbsUp_SwitchPlates-B_Adhes.gbr, ThumbsUp_SwitchPlates-B_CrtYd.gbr, ThumbsUp_SwitchPlates-B_Cu.gbr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]
2025-05-28 Generated Gerbers for all three switch plates which were accepted by JLCPCB without extra 'large size' charges.
    [ThumbsUp_SwitchPlates-B_Cu.gbr, ThumbsUp_SwitchPlates-B_Mask.gbr, ThumbsUp_SwitchPlates-B_Paste.gbr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]
2025-05-28 Added the diode direction wherever it was missed.
    [ThumbsUp v11 BOM.csv, ThumbsUp v8 BOM.xls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]
2025-05-28 Corrected two switch support plates as per JLCPCB'S FEEDBACK..
    [ThumbsUp-B_Cu.gbr, ThumbsUp-B_Mask.gbr, ThumbsUp-B_Paste.gbr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]
2025-06-06 Added photos of v11 in different stages of readiness.
    [ThumbsUp_SwitchPlates-B_Cu.gbr, ThumbsUp_SwitchPlates-B_Mask.gbr, ThumbsUp_SwitchPlates-B_Paste.gbr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]
2026-05-29 v11: Added STEP file for the bottom board outline
    [ThumbsUp_v11.step]
2026-11-10 K11/K5/K8 Added the most current version of the firmware.
